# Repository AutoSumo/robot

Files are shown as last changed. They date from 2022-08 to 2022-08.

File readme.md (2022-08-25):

# AutoSumo Robot

Robot used in the AutoSumo arena. Remote controlled by the [Bot Server](https://github.com/AutoSumo/server) using websockets.

```mermaid
flowchart TD
    web["🌐 Web Interface"] -->|uploads code| code-server[("💾 Code Server")]
    code-server -->|highlight data| web
    code-server -->|downloads code| bot-server["💻 Bot Server"]
    bot-server -->|highlight data| code-server
    bot-server -->|motor instructions| robot["🤖 Robot\n(this)"]
    robot -->|sensor data| bot-server
    tag-server["📷 Tag Server"] -->|apriltag positions| bot-server
    
    style robot stroke-width:2px,stroke-dasharray: 5 5,stroke:#3b82f6
    
    click web "https://github.com/AutoSumo/web"
    click code-server "https://github.com/AutoSumo/code-server"
    click bot-server "https://github.com/AutoSumo/server"
    click tag-server "https://github.com/AutoSumo/tag-server"
```

https://user-images.githubusercontent.com/26680599/185769401-c024f6a5-496c-4001-9858-a5e7ccef9a41.mp4

### Hardware

 - ESP32 used for communication and processing
 - Dual H-Bridge motor driver chosen for size and efficiency
 - Back-mounted rechargable battery
 - Two DC motors for drive
 - Two infrared line sensors mounted to the front of the robot
 - Single-point LIDAR mounted to a servo with a 180 degree range of motion
 - Two infrared tachometers (one for each wheel)

Robot body is fully 3D printed and assembled using M3 screws and nuts. Designed using Fusion 360.

Robot body in Fusion 360
Picture of the robot
Picture of the underside of the robot

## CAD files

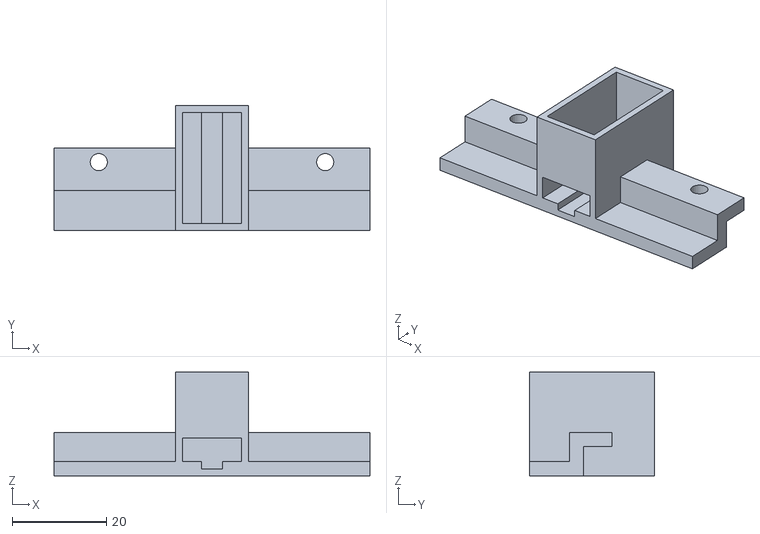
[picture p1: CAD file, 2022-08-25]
3d/bodies/Servo Mount.stl
67.0 x 26.5 x 22.0

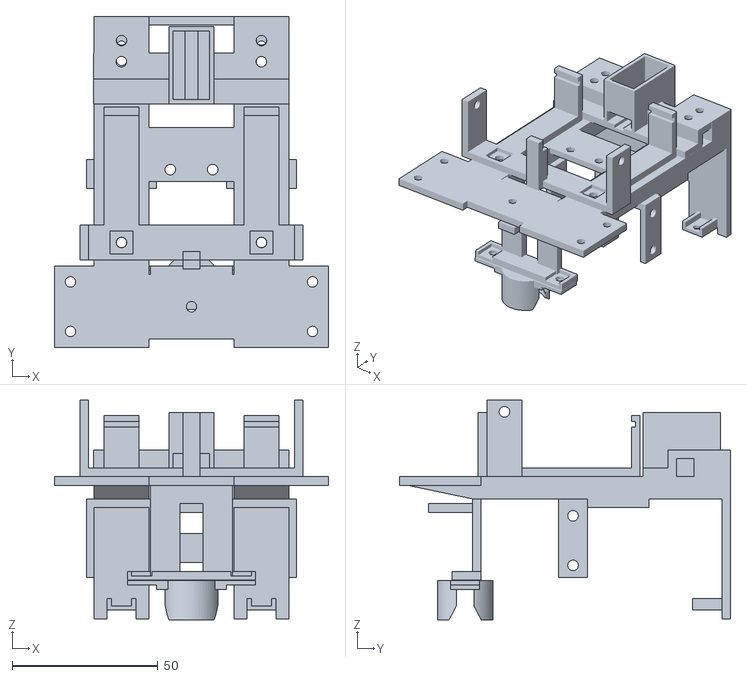
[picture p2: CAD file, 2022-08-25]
3d/robot.stl
94.0 x 113.5 x 75.3

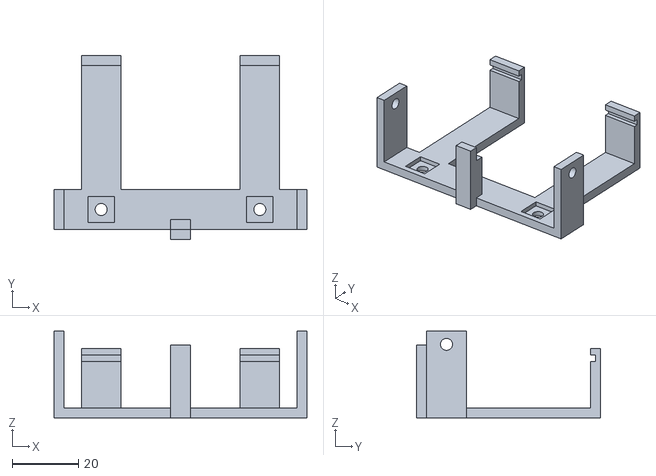
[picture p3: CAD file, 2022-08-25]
3d/bodies/Protoboard Mount.stl
76.5 x 55.5 x 26.2

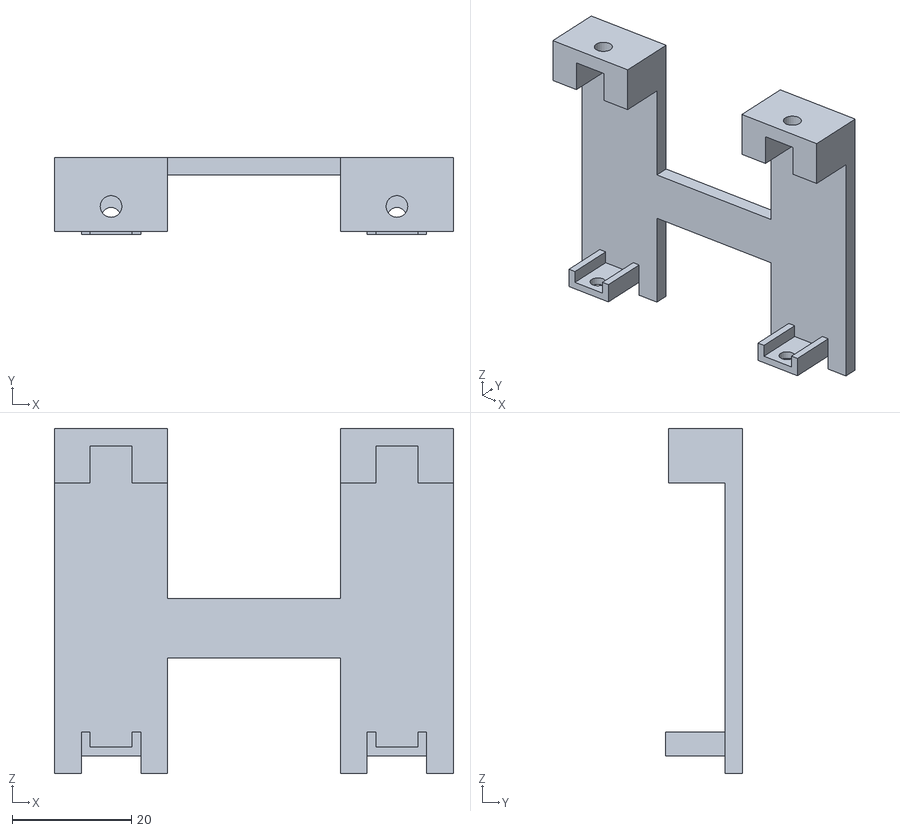
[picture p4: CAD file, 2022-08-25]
3d/bodies/IR Front Mount.stl
67.0 x 13.0 x 58.0

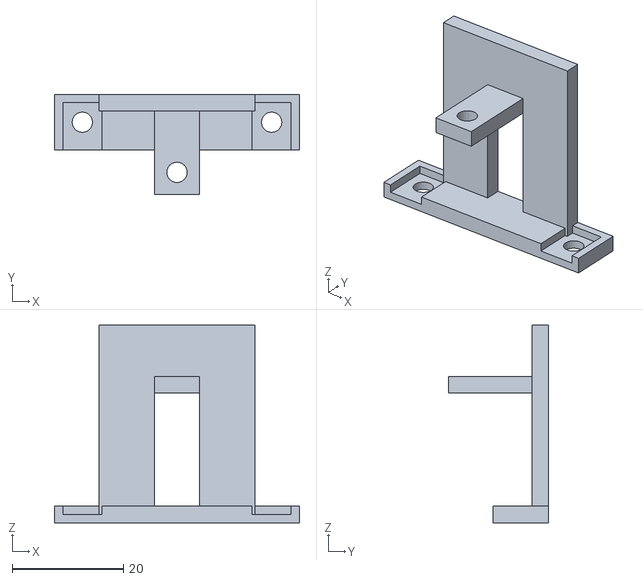
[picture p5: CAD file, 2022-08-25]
3d/bodies/Back Caster Mount.stl
44.0 x 18.0 x 35.5

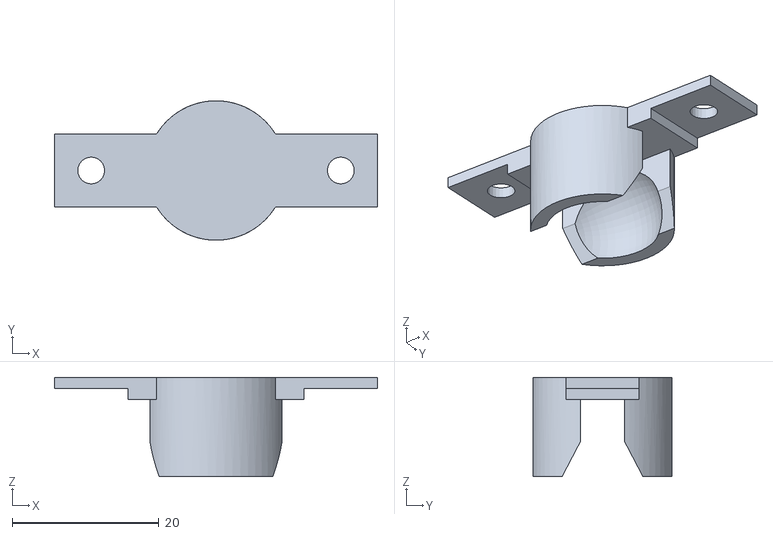
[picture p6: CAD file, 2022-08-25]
3d/bodies/Back Caster.stl
44.0 x 19.0 x 13.5

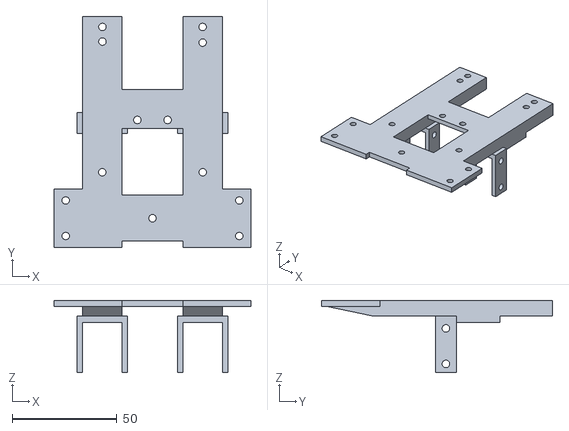
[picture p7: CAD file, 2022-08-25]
3d/bodies/Dual Motor Mount.stl
94.0 x 110.5 x 34.6

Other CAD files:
3d/robot.f3z

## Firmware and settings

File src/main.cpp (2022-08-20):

#include <Arduino.h>
#include <ESP32Servo.h>
#include <Wire.h>
#include "Adafruit_VL6180X.h"
#include <WiFi.h>
#include <WebSocketsClient.h>
#include <esp_wifi.h>
#include "connection-details.h"
#include "packets.h"


#define DRIVER_STANDBY 19

#define DRIVER_PWM_A 22
#define DRIVER_PWM_CHANNEL_A 14
#define DRIVER_IN_1_A 21
#define DRIVER_IN_2_A 23

#define DRIVER_PWM_B 17
#define DRIVER_PWM_CHANNEL_B 15
#define DRIVER_IN_1_B 18
#define DRIVER_IN_2_B 5

#define SERVO_PIN 16

#define LEFT_TACH_A 35
#define LEFT_TACH_D 34
#define RIGHT_TACH_A 39
#define RIGHT_TACH_D 36

#define IR_LEFT 33
#define IR_RIGHT 32

#define LIDAR_SDA 27
#define LIDAR_SCL 26
#define LIDAR_INT 25


#define SPEED_TIMEOUT_MS 1000
#define LIDAR_INTERVAL 100

int leftSpeed = 0;
int rightSpeed = 0;
unsigned long lastSpeedRequest = 0;
bool speedUpdated = false;

uint8_t servoPos = 90;
bool servoUpdated = false;

bool lastIRLeft = false;
bool lastIRRight = false;

unsigned long lidarLastSent = 0;

WebSocketsClient webSocket;
Servo servo;

Adafruit_VL6180X vl = Adafruit_VL6180X();
TwoWire lidarTwoWire = TwoWire(0);

void onWebSocketEvent(WStype_t type, uint8_t * payload, size_t length) {
	switch(type) {
		case WStype_DISCONNECTED:
			Serial.println("Disconnected from websocket!");
			break;
		case WStype_CONNECTED:
			Serial.println("Connected to websocket!");
            webSocket.sendTXT(ROBOT_ID);
			break;
		case WStype_TEXT:
            // Send text data back
            webSocket.sendTXT((char*) payload);
			break;
		case WStype_BIN:
            if(length < 1) break;

            PacketType packetType;
            memcpy(&packetType, payload, sizeof(PacketType));

            if(packetType == MOVE_MOTORS) {
                if(length < (sizeof(MoveMotorsPacket) + 1)) break;

                MoveMotorsPacket packet;
                memcpy(&packet, payload+1, sizeof(MoveMotorsPacket));
                leftSpeed = packet.leftPower * (packet.leftDirection == 1 ? 1 : -1);
                rightSpeed = packet.rightPower * (packet.rightDirection == 1 ? 1 : -1);
                lastSpeedRequest = millis();
                speedUpdated = true;
            } else if (packetType == MOVE_SERVO) {
                if(length < (sizeof(MoveServoPacket) + 1)) break;

                MoveServoPacket packet;
                memcpy(&packet, payload+1, sizeof(MoveServoPacket));
                servoPos = packet.angle;
                servoUpdated = true;
            }
            
			break;
		case WStype_ERROR:			
            Serial.println("Websocket error!");
            break;
		case WStype_FRAGMENT_TEXT_START:
		case WStype_FRAGMENT_BIN_START:
		case WStype_FRAGMENT:
		case WStype_FRAGMENT_FIN:
		case WStype_PING:
		case WStype_PONG:
			break;
	}

}

void websocketTask(void *pvParameters) {
    // Connect to websocket server
    Serial.print("WS running on core ");
    Serial.println(xPortGetCoreID());

    webSocket.onEvent(onWebSocketEvent);
    webSocket.begin(WEBSOCKET_IP, WEBSOCKET_PORT, "/");
    while(true) {
        webSocket.loop();
    }
}

TaskHandle_t wsTask;

void setup() {
    Serial.begin(115200);
    Serial.println("");

    // Setup pins
    // Motor driver
    pinMode(DRIVER_IN_1_A, OUTPUT);
    pinMode(DRIVER_IN_2_A, OUTPUT);
    pinMode(DRIVER_IN_1_B, OUTPUT);
    pinMode(DRIVER_IN_2_B, OUTPUT);

    pinMode(DRIVER_STANDBY, OUTPUT);

    ledcAttachPin(DRIVER_PWM_A, DRIVER_PWM_CHANNEL_A);
    ledcSetup(DRIVER_PWM_CHANNEL_A, 5000, 8);

    ledcAttachPin(DRIVER_PWM_B, DRIVER_PWM_CHANNEL_B);
    ledcSetup(DRIVER_PWM_CHANNEL_B, 5000, 8);

    digitalWrite(DRIVER_STANDBY, HIGH);

    // IR sensors
    pinMode(IR_LEFT, INPUT);
    pinMode(IR_RIGHT, INPUT);

    // Servo
    servo.attach(SERVO_PIN);

    // Lidar
    lidarTwoWire.begin(LIDAR_SDA, LIDAR_SCL, (uint32_t) 100000);
    vl.begin(&lidarTwoWire);

    // Connect to wifi
    esp_wifi_set_ps(WIFI_PS_NONE);
    Serial.print("Connecting to ");
    Serial.println(WIFI_SSID);
    WiFi.begin(WIFI_SSID, WIFI_PASSWORD);
    while(WiFi.status() != WL_CONNECTED) {
        Serial.print(".");
        delay(500);
    }
    Serial.println("");
    Serial.print("Connected! IP address: ");
    Serial.println(WiFi.localIP());

    xTaskCreatePinnedToCore(websocketTask, "WS Task", 10000, NULL, 0, &wsTask, 0);
}

void sendIR(bool left, bool right) {
    IRDataPacket irDataPacket;
    irDataPacket.type = IR_DATA;
    irDataPacket.left = left;
    irDataPacket.right = right;

    webSocket.sendBIN((uint8_t*) &irDataPacket, sizeof(IRDataPacket));
}

void sendLidar(uint8_t range, uint8_t status) {
    LidarDataPacket lidarDataPacket;
    lidarDataPacket.type = LIDAR_DATA;
    lidarDataPacket.range = range;
    lidarDataPacket.status = status;
    webSocket.sendBIN((uint8_t*) &lidarDataPacket, sizeof(LidarDataPacket));
}

void loop() {
    delay(1);

    unsigned long now = millis();

    if(now - lastSpeedRequest >= SPEED_TIMEOUT_MS) {
        leftSpeed = 0;
        rightSpeed = 0;
        speedUpdated = true;
    }

    if(speedUpdated) {
        if(leftSpeed > 0) {
            digitalWrite(DRIVER_IN_1_A, LOW);
            digitalWrite(DRIVER_IN_2_A, HIGH);
        } else {
            digitalWrite(DRIVER_IN_1_A, HIGH);
            digitalWrite(DRIVER_IN_2_A, LOW);
        }
        ledcWrite(DRIVER_PWM_CHANNEL_A, abs(leftSpeed));

        if(rightSpeed > 0) {
            digitalWrite(DRIVER_IN_1_B, LOW);
            digitalWrite(DRIVER_IN_2_B, HIGH);
        } else {
            digitalWrite(DRIVER_IN_1_B, HIGH);
            digitalWrite(DRIVER_IN_2_B, LOW);
        }
        ledcWrite(DRIVER_PWM_CHANNEL_B, abs(rightSpeed));

        speedUpdated = false;
    }

    if(servoUpdated) {
        servo.write(servoPos);
        servoUpdated = false;
    }

    if(webSocket.isConnected()) {
        // Read and send IR data
        bool irLeft = digitalRead(IR_LEFT) == HIGH ? true : false;
        bool irRight = digitalRead(IR_RIGHT) == HIGH ? true : false;
        if(irLeft != lastIRLeft || irRight != lastIRRight) {
            lastIRLeft = irLeft;
            lastIRRight = irRight;
            sendIR(irLeft, irRight);
        }

        // Send LiDAR data
        if(now - lidarLastSent > LIDAR_INTERVAL) {
            uint8_t range = vl.readRange();
            uint8_t status = vl.readRangeStatus();
            sendLidar(range, status);
            lidarLastSent = now;

            sendIR(digitalRead(IR_LEFT) == HIGH ? true : false, digitalRead(IR_RIGHT) == HIGH ? true : false);
        }
    }
}

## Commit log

2022-05-12 initial esp32 pio base
2022-05-12 add basic websocket motor packet
2022-05-12 move motors and add IR packet
2022-05-12 add servo packet
2022-05-13 add lidar packet
2022-05-13 change servo library and motor pwm channels
2022-08-25 add 3d files
    [Back Caster Mount.stl, Back Caster.stl, Dual Motor Mount.stl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]
